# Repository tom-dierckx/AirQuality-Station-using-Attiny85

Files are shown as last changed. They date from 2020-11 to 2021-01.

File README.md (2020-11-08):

# Battery powered portable air quality station

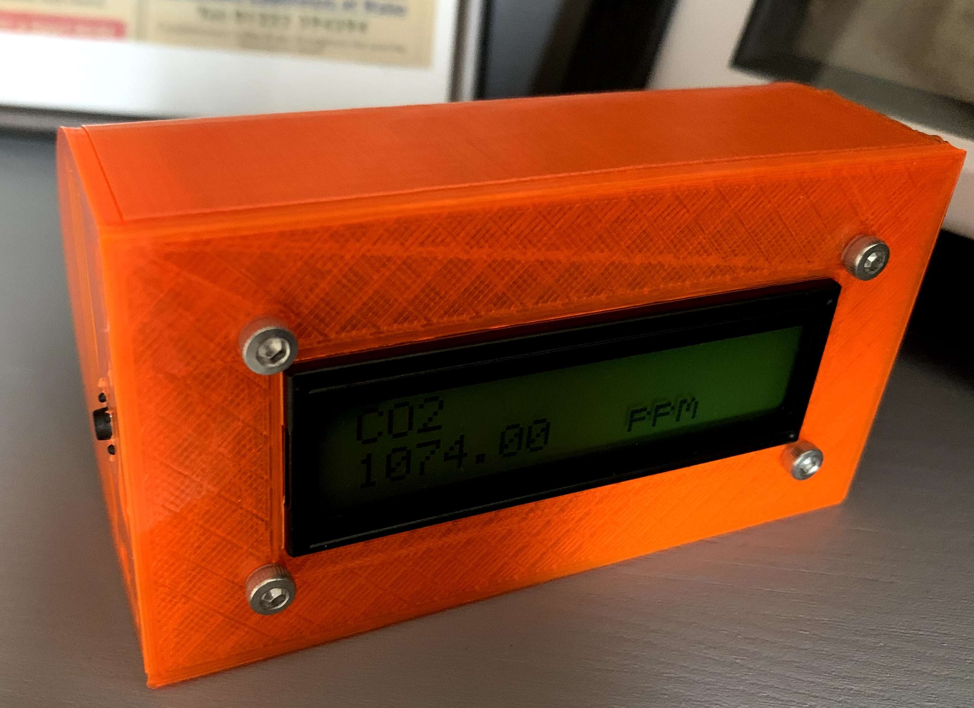
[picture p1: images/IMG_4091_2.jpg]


As we have all been more indoors during the COVID crisis. Keeping rooms well ventilated is important, I built this station as a reminder to open my window from time to time.
**Warning**: to get precise measurements you will want to calibrate the sensors against known sources!

This setup is capable of measuring: CO2, Volatile organic compounds, temperature (degrees Celsius this can be changed in code), humidity and barometric pressure. As this uses i2c to connect to the sensors any other i2c 3.3V enabled sensor can probably be used (the attiny85 memory is the only limiting factor here).

This is a revision of an Air quality station that I build during the initial lockdown in March that I have been using to monitor the indoor air levels. The old version was based around the CCS811 and the DHT22 sensor. I wasn't happy about the code so I only published the DHT22 part [here](https://github.com/tom-dierckx/DHT-attiny85-i2c) and the 3d printed case [here](https://www.thingiverse.com/thing:4262574).

We are in a lock-down again so it was time for a revision, a portable version powered by a battery. This time I removed some unused features (previous version could store on an SD card using SPI) and switched the Arduino mini with an Attiny85 running on a lower clock (1 Mhz internal).  
I also changed the DHT22 to the much more accurate and also i2c enabled BME280 sensor.

## Components

### Sensors

I used breakouts of the following sensors acquired on Aliexpress.

CCS811 3.3V version [datasheet](https://cdn.sparkfun.com/assets/learn_tutorials/1/4/3/CCS811_Datasheet-DS000459.pdf):
- CO2 particles in the air
- Volatile organic compounds

BME280 3.3V version [datasheet](https://www.bosch-sensortec.com/media/boschsensortec/downloads/datasheets/bst-bme280-ds002.pdf):
- Temperature
- Humidity
- Air pressure

Both of these breakouts expose an i2c interface (and spi) that we will use.

### Other electric components/modules

Items needed for the electronic circuit:
- LCD display 16 x 2 with the i2c interface attached.
- Attiny85
- Lithium battery charger (based on the TP4056)
- Lithium Ion Battery (Type 18650)
- Red LED (for debugging)
- Resistor 1K Ohm 
- Resistor 10K Ohm
- Button
- PCB Prototype Matrix

And 4 x M3 nuts and bolts for connecting the display to the case.

Printable components:

Battery case: I used this 18650 battery case that I found on Thingiverse [here](https://www.thingiverse.com/thing:535688) it worked well even if it is deprecated (used aluminium from a coca cola can as leads).

Arduino UNO for programming the attiny85 and a 10uF electrolytic capacitor.

As I'm just doing this in my spare time I just use my glue gun to fix everything in place. So if you do not change the models you are going to need a glue gun and a lot of glue :D.

### Connecting everything together.

#### Schematic

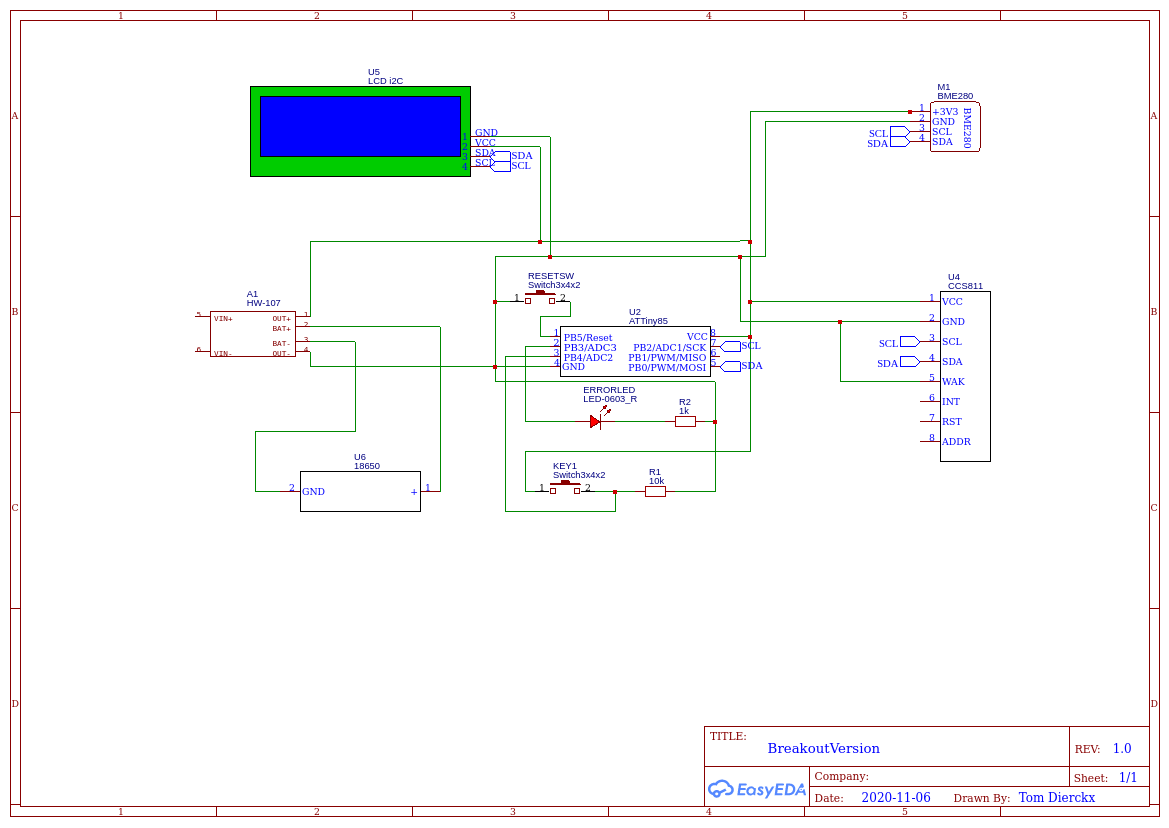
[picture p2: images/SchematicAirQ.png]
Schematic


I just connected all the i2c interfaces together. And attached the button and a red LED to the attiny85. The red led is the `errorPin` in code and will get lit when the attiny cannot setup a connection with a sensor.

The button is used to cycle all the sensor values on the display.

### Assembling the display and logic

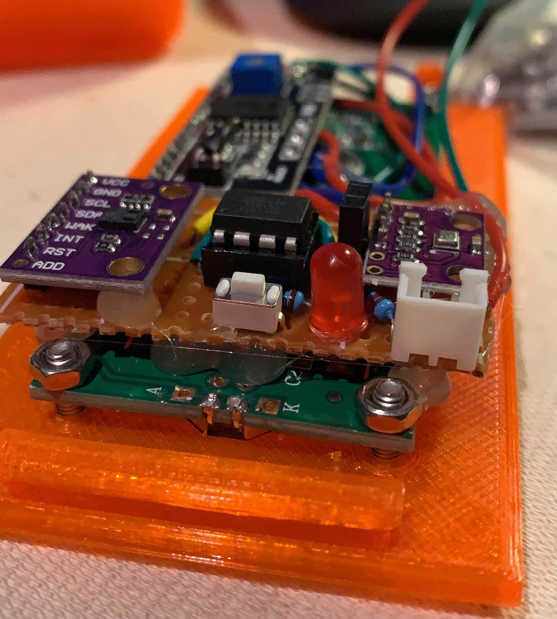
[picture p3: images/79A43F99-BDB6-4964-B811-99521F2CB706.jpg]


Solder all parts together as shown on the picture. I added a lot of hotglue and tried to not create any shorts.

### Assembling the battery holder charching module and button

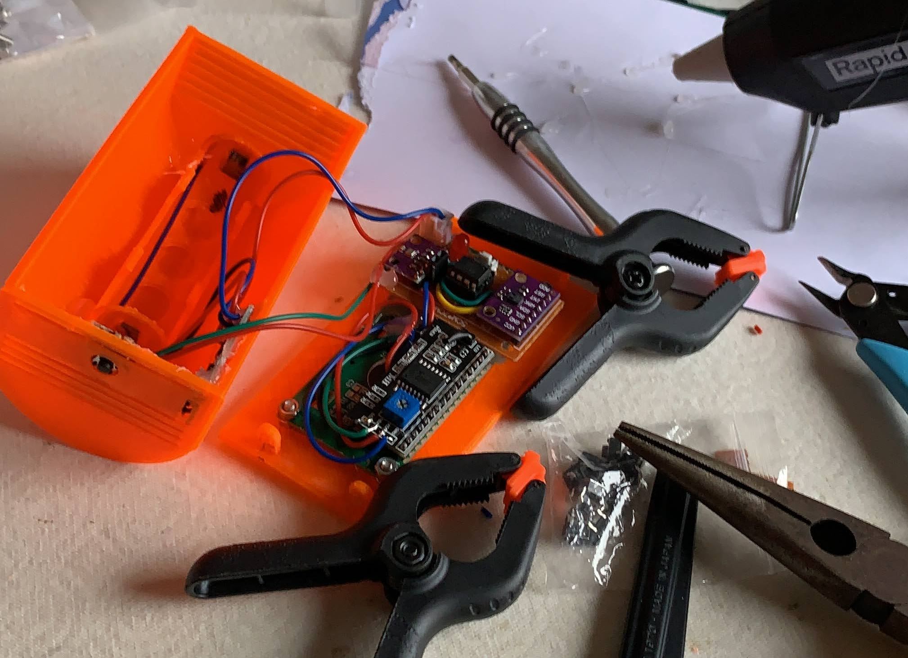
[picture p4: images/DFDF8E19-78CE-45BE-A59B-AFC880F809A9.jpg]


Again using hotglue is key :D

## Code part

Just import this repository in platformIO and you should be good to go, the code isn't that complex. If you have any questions you can always contact me on Github.

I used this [documentation](https://create.arduino.cc/projecthub/arjun/programming-attiny85-with-arduino-uno-afb829) for flashing an Attiny85 using an arduino UNO. 

Settings in the `platformio.ini` file work with this method (Do not forget the electrolytic capacitor!).

### Attiny85 bootloader

I installed the bootloader with the 1Mhz internal clock configuration this is the lowest clock (the lower the clock the lower the powerconsumption) before making the code unstable.

## Can we finally build the thing please

I uploaded the STL files to Thingiverse. You can find these [here](https://www.thingiverse.com/thing:4645516).
Or in the `/images` directory.

The STL files are also added to this directory in the `3ddesigns`

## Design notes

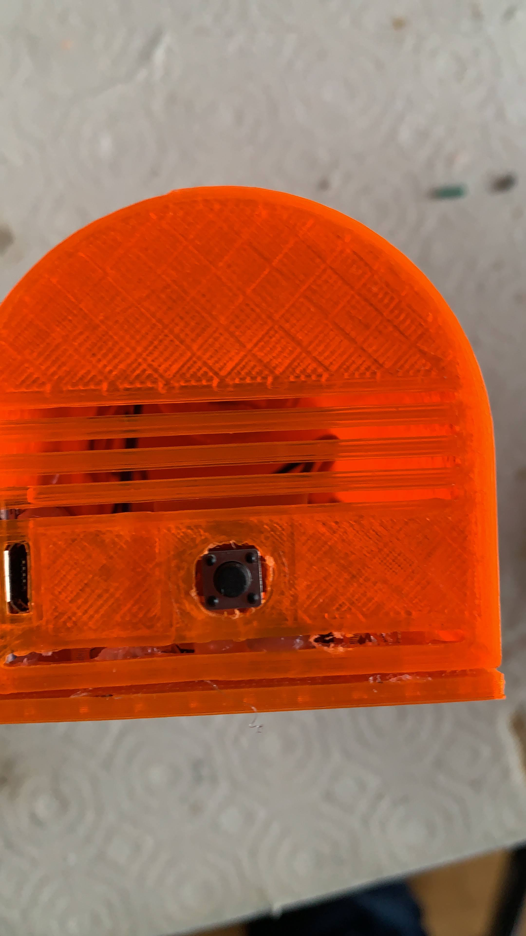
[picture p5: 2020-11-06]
images/74FB2B77-159F-4036-B8A1-282C9C34806A.jpg

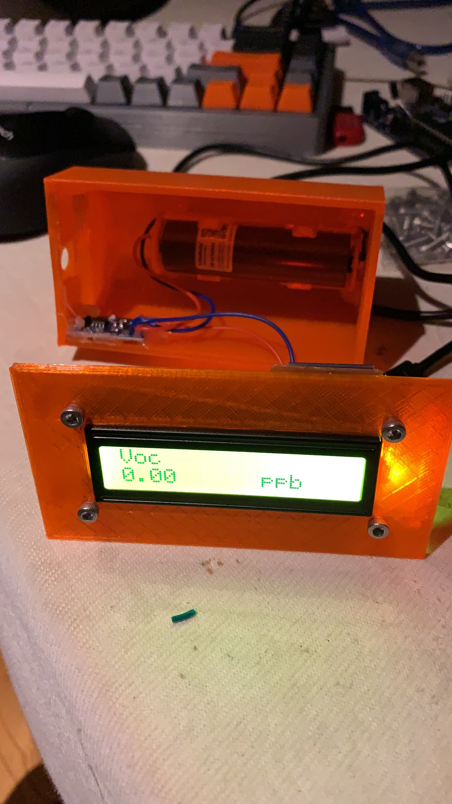
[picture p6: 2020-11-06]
images/32D0AA7C-EDE6-487A-A927-82D538B2B0A6.jpg

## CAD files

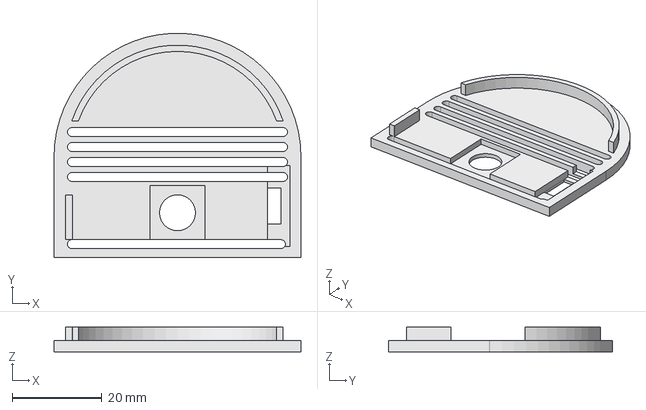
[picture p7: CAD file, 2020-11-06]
3ddesigns/AirQProjectLeftLid.FCStd
55.1 x 50.0 x 5.50 mm

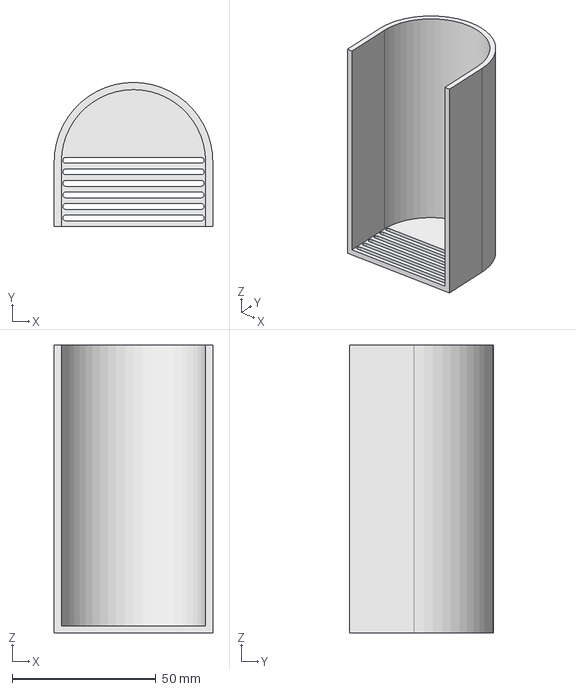
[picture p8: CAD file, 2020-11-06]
3ddesigns/AirQProjectBase.FCStd
55.1 x 50.1 x 100.0 mm

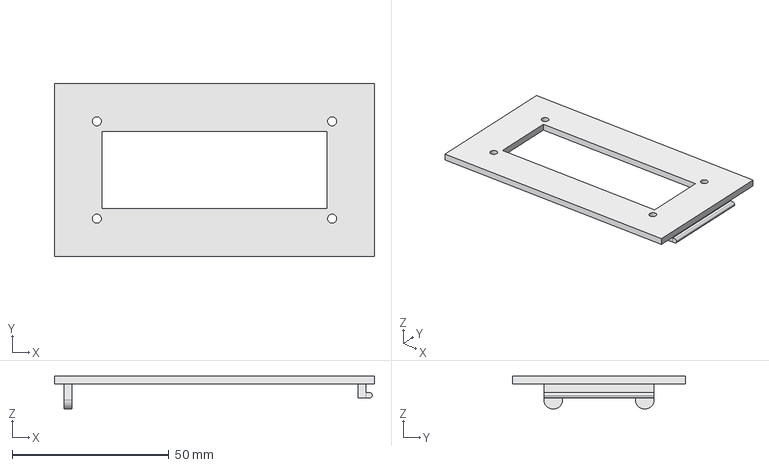
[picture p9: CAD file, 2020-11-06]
3ddesigns/AirQProjectTop.FCStd
102.0 x 55.2 x 10.5 mm

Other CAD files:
3ddesigns/AirQProjectBase.stl
3ddesigns/AirQProjectLeftLid.stl
3ddesigns/AirQProjectTop.stl

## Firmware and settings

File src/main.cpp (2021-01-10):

#include <Arduino.h>

#include <LiquidCrystal_I2C.h>
// CCS811 class
#include "Adafruit_CCS811.h"

// Requires headers for AVR defines and ISR function
// #include <avr/io.h>
// #include <avr/interrupt.h>
#include <avr/sleep.h>
#define adc_disable() (ADCSRA &= ~(1<<ADEN))

// libs for BME280
// #include <Adafruit_BME280.h>
#define TINY_BME280_I2C
#include "TinyBME280.h"
tiny::BME280 bme;

bool sensorsReadyState = false;  // state if sensors are heated


   // pin used for button to cycle in the menu
// debug pins
const uint8_t errorPin = 3;

// button logic
const uint8_t buttonPin = 4;
boolean buttonState = LOW;
boolean lastButtonState = LOW;

// the following variables are unsigned longs because the time, measured in
// milliseconds, will quickly become a bigger number than can be stored in an int.
unsigned long lastDebounceTime = 0;  // the last time the output pin was toggled
unsigned long debounceDelay = 50;    // the debounce time; increase if the output flickers

uint8_t menuSelectedSensor = 0;
uint8_t oldSelectedMenu = 0;


// i2c addresses
const uint8_t lcdAddr = 0x27;
const uint8_t ccs811Addr = 0x5A;
const uint8_t bme280Addr = 0x76;
// bootup screen dot logic
const unsigned short bootingDotsdelay = 1000;
unsigned long previousbootinMillis = 0;
uint8_t bootingdots = 0;
LiquidCrystal_I2C lcd(lcdAddr, 16, 2);

// Adafruit_BME280 bme;
Adafruit_CCS811 ccs;

// total sensor types
const uint8_t amountOfSensors = 5;
double sensorOutputResults[amountOfSensors];
const char sensorNames[amountOfSensors][8] = {
  "CO2", 
  "Voc", 
  "Temp",
  "Humid",
  "Press"
};
// order has to match sensorNames
const char sensorValueUnit[amountOfSensors][4] = {
  "ppm", 
  "ppb", 
  "C",
  "%",
  "hPa"
};

// sensor polling interval
const unsigned short sensorPollingInterval = 15000;
unsigned long previousPollingMillis = 0;

// lcd variable
unsigned long previousButtonPressMillis = 0;
const unsigned short lcdTimeToSleep = 5000;

// declare before setup so calling is possible => https://community.platformio.org/t/order-of-function-declaration/4546/2
// void handleButtonPress();

void setup() {
  pinMode(errorPin, OUTPUT);
  digitalWrite(errorPin, LOW);
  if(!ccs.begin()){
    digitalWrite(errorPin, HIGH);
    while(1);
  }
  ccs.setDriveMode(CCS811_DRIVE_MODE_10SEC);
  if (!bme.beginI2C(bme280Addr)) {
		digitalWrite(errorPin, HIGH);
    while(1);
	}
  // make sensor sleep for low power
  bme.setMode(tiny::Mode::SLEEP);
  // disable ADC no need for it 
  adc_disable();
  lcd.init();
  lcd.backlight();
}

void showBootLoop(){
  lcd.setCursor(0, 0);
  lcd.backlight();  
  lcd.print("Heating sensors");
}

void button_logic() {
  boolean reading = digitalRead(buttonPin);

  // check to see if you just pressed the button
  // (i.e. the input went from LOW to HIGH), and you've waited long enough
  // since the last press to ignore any noise:

  // If the switch changed, due to noise or pressing:
  if (reading != lastButtonState) {
    // reset the debouncing timer
    lastDebounceTime = millis();
  }

  if ((millis() - lastDebounceTime) > debounceDelay) {
    // whatever the reading is at, it's been there for longer than the debounce
    // delay, so take it as the actual current state:

    // if the button state has changed:
    if (reading != buttonState) {
      buttonState = reading;

      // only toggle the LED if the new button state is HIGH
      if (buttonState == HIGH) {
        menuSelectedSensor++;
      }
    }
  }
  lastButtonState = reading;
}

void view() {
  // This method handles all the UI stuff 
  // button changed in the last 20 millis it got pressed and we need to refresh the display
  unsigned long currentMillis = millis();

  // Serial.print("Currently selected menu");
  // Serial.println(menuSelectedSensor);
  if(oldSelectedMenu != menuSelectedSensor) {
    // change detected clear lcd for new data
    lcd.clear();
    lcd.backlight();
    // reset timer
    previousButtonPressMillis = currentMillis;
  }
  oldSelectedMenu = menuSelectedSensor;
  
  if (currentMillis - previousButtonPressMillis > lcdTimeToSleep ) {
     lcd.noBacklight();
  }

  if (menuSelectedSensor >= amountOfSensors) {
    menuSelectedSensor = 0;
    lcd.clear();
  }
  lcd.setCursor(0, 0);
  lcd.print(sensorNames[menuSelectedSensor]);
  lcd.setCursor(0, 1);
  lcd.print(sensorOutputResults[menuSelectedSensor]);
  lcd.setCursor(10, 1);
  lcd.print(sensorValueUnit[menuSelectedSensor]);
  // reset when overshooting amount of sensors
}

void sensorLogic() {
  // reading data from dht
  unsigned long currentMillis = millis();
  // this means reading out sensor values if possible or reading data that is already present (like DSM501)
  if(currentMillis - previousPollingMillis > sensorPollingInterval) {
    previousPollingMillis = currentMillis; 
    /* 
    
          reading data from ccs811 sensor 

    */
    if(ccs.available()){
      if(!ccs.readData()){
        sensorOutputResults[0] = ccs.geteCO2();
        sensorOutputResults[1] = ccs.getTVOC();
      }
      else{
        digitalWrite(errorPin, HIGH);
      }
    }
    bme.setMode(tiny::Mode::FORCED);
    // wait for mesurement
    while(bme.isMeasuring() == false) ; //Wait for sensor to start measurment
    while(bme.isMeasuring() == true) ; //Hang out while sensor completes the reading
    sensorOutputResults[2] = bme.readFixedTempC() / 100.0;
    sensorOutputResults[3] = bme.readFixedHumidity()/ 1000.0;
    sensorOutputResults[4] = bme.readFixedPressure() / 100.0;
    // Add environment measurements to ccs the casting doesn't do any rounding only 8 bytes left so I'm willing to accept the error
    ccs.setEnvironmentalData((uint8_t) sensorOutputResults[3],sensorOutputResults[2]);
  }

}

void loop() {
  view();
  sensorLogic();
  button_logic();
}

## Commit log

2020-03-25 writing sensor result to sd card
2020-03-26 switching csv to a usable format
2020-03-27 switching button pres to interrupt for faster UI
2020-03-29 removing stuff and switching to 2 sensors
2020-07-20 ESP32 compatible version
    Using BME280 instead of the DHT22 sensor
2020-08-05 Switching airQ status to core 1 Will add webserver next
2020-10-04 removing the multithreading it didnt work well Core 1 also needs to do the i2c handling
2020-11-06 adding images and 3d drawings
    [AirQProjectBase.FCStd, AirQProjectBase.stl, AirQProjectLeftLid.FCStd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]
2020-11-06 adding schematic
2021-01-10 adding environment data to ccs sensor
